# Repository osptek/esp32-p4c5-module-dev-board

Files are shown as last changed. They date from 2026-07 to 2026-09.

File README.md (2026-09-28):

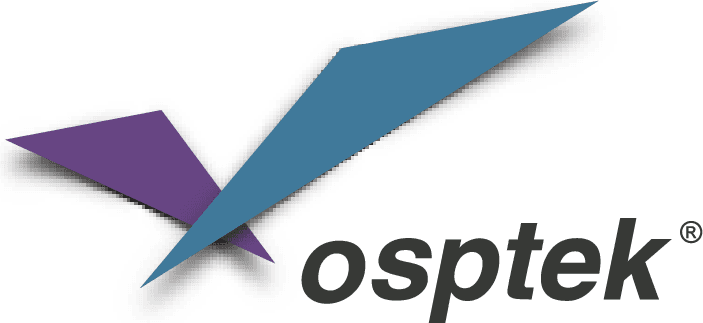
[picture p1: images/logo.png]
OSPTEK


<h1 align="center">OSPTEK ESP32-P4C5-Module 开发板</h1>

<p align="center"><b>开箱即用 · 多功能扩展 · 全接口引出</b></p>

<p align="center"><a href="./README_EN.md">English</a> | 简体中文</p>

<p align="center">
  
  
  
  
  
</p>

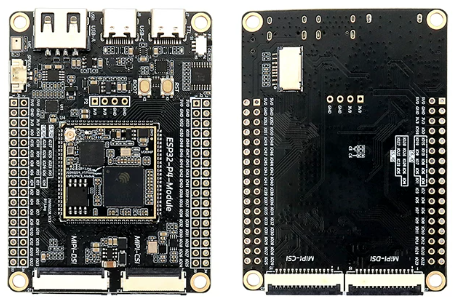
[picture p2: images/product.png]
OSPTEK ESP32-P4C5-Module 开发板产品图


## 目录

- [产品简介](#产品简介)
- [产品特性](#产品特性)
- [应用场景](#应用场景)
- [规格参数](#规格参数)
- [硬件资源](#硬件资源)
- [搭载核心板](#搭载核心板)
- [已适配屏幕](#已适配屏幕)
- [已适配摄像头](#已适配摄像头)
- [快速开始](#快速开始)
- [仓库结构](#仓库结构)
- [相关资料](#相关资料)
- [购买链接](#购买链接)
- [技术支持](#技术支持)

---

## 产品简介

OSPTEK ESP32-P4C5-Module 开发板是一款以 **ESP32-P4C5 核心板** 为核心的多功能开发平台。
底板在核心板基础上扩展出摄像头、显示屏、音频、USB 等外设接口与多重电源保护电路，
并通过 2×2×17 排针引出 ESP32-P4 的 55 个可编程 GPIO 及 ESP32-C5 的 9 个 GPIO，
省去自行设计底板的工作，可直接用于方案评估与二次开发。

核心板搭载的 ESP32-P4 内置 2 个高性能（HP）RISC-V 内核和 1 个低功耗（LP）内核，主频高达 400 MHz，
集成 JPEG 编解码器、像素处理加速器（PPA）、图像信号处理器（ISP）与 H.264 视频编码器；
配合 ESP32-C5 提供 Wi-Fi 6（2.4/5 GHz 双频）、蓝牙 5（LE）与 IEEE 802.15.4（Zigbee / Thread）无线连接。

## 产品特性

- 🚀 **开箱即用**：核心板 + 底板一体，无需自行设计底板，上电即可评估与开发
- ⚡ **高性能双核**：ESP32-P4 双核 RISC-V 处理器，主频高达 400 MHz，16 MB Flash + 32 MB PSRAM
- 🎨 **强大多媒体**：集成 JPEG 编解码、H.264 视频编码、PPA、ISP，胜任图像与视频处理
- 📶 **无线连接**：Wi-Fi 6（2.4/5 GHz 双频）、蓝牙 5（LE）、IEEE 802.15.4（Zigbee / Thread）
- 📷 **摄像头接口**：MIPI-CSI 24P 接口 + 15P 树莓派兼容接口，可直接接入 SC2336 摄像头
- 🖥️ **显示接口**：MIPI-DSI 30P 接口 + 15P 树莓派兼容接口，支持 YDP400BT001-V4 屏幕
- 🔊 **完整音频链路**：ES8311 编解码器 + NS4150 3W D 类功放 + 板载硅麦，录音放音开箱可用
- 🔌 **丰富 USB**：2 × Type-C（数据 / 调试）+ USB-A Host，支持高速 USB 2.0 切换
- 🛠️ **免接线调试**：板载 CH343P USB 转串口，模拟开关一键切换 P4 / C5 烧录目标
- 📍 **全引脚引出**：2×2×17 排针引出 ESP32-P4 的 55 个可编程 GPIO 与 ESP32-C5 的 9 个 GPIO
- 🛡️ **电源保护**：双路理想二极管防止电流倒灌，USB-A 输出口带过流与短路保护

## 应用场景

- 🖥️ HMI 人机交互
- 📷 视觉识别与图像采集
- 🎙️ 语音交互与音频处理
- 📹 视频编码与流媒体传输
- 🏠 智能家居中控面板
- 🏭 工业控制与设备监控
- 🤖 电子机器人
- 🧠 AIoT 边缘计算
- 🔌 USB 主机扩展

## 规格参数

### 主控与存储

| 项目 | 规格 |
| --- | --- |
| 核心板 | ESP32-P4C5 核心板（88 Pin 邮票孔） |
| 主控 | 乐鑫 ESP32-P4（2 × HP RISC-V + 1 × LP 内核） |
| 主频 | 高达 400 MHz |
| ROM | 128 KB HP ROM + 16 KB LP ROM |
| SRAM | 768 KB HP L2MEM + 32 KB LP SRAM + 8 KB TCM |
| Flash | 16 MB 串行 NOR Flash |
| PSRAM | 32 MB（ESP32-P4 片内叠封） |

### 无线

| 项目 | 规格 |
| --- | --- |
| 无线芯片 | ESP32-C5 |
| Wi-Fi | Wi-Fi 6（2.4 / 5 GHz 双频） |
| 蓝牙 | 蓝牙 5（LE） |
| 其他协议 | IEEE 802.15.4（Zigbee / Thread） |
| 天线 | 核心板板载 IPEX-1 天线接口 |

### 摄像头与显示

| 项目 | 规格 |
| --- | --- |
| 摄像头（正面） | MIPI-CSI 24P 0.5 mm 上下接，支持 SC2336 |
| 摄像头（背面） | MIPI-CSI 15P 1.0 mm 上下接，兼容树莓派接口 |
| 显示屏（正面） | MIPI-DSI 30P 0.5 mm 上下接，支持 YDP400BT001-V4  |
| 显示屏（背面） | MIPI-DSI 15P 1.0 mm 上下接，兼容树莓派接口 |
| 背光驱动 | SY7200 升压恒流，为 DSI 屏幕提供恒流背光 |

### 音频

| 项目 | 规格 |
| --- | --- |
| 编解码器 | ES8311（低功耗高性能单声道 Codec） |
| 功放 | NS4150（3 W 单声道 D 类） |
| 麦克风 | LMA3729T421-OA1 硅基麦克风（板载） |
| 扬声器接口 | MX1.25-2P 座子 |

### USB 与调试

| 项目 | 规格 |
| --- | --- |
| 数据口 | Type-C × 1，高速 USB 2.0（480 Mbps） |
| 调试口 | Type-C × 1，板载 CH343P USB 转 UART |
| USB Host  | USB-A × 1 |
| 通道切换  | TS3USB221ARSER 1:2 多路复用，Type-C 与 USB-A 间切换 |
| 烧录切换  | 拨动开关：往上拨烧录 ESP32-P4，往下拨烧录 ESP32-C5 |

### 电源管理

| 项目 | 规格 |
| --- | --- |
| 主电源 | 5 V 输入，TLV62569 降压至 3.3 V |
| 防倒灌 | LM66200DRLR 双路理想二极管（ORing 逻辑） |
| USB-A 输出 | MT9700 可调限流功率分配开关，带过流与短路保护 |
| 辅助电源 | 板载 1.8 V / 2.8 V LDO，供摄像头等外设使用 |

### 扩展接口

| 项目 | 规格 |
| --- | --- |
| 扩展排针  | 2 × 2×17P，2.54 mm 间距 |
| 引出 GPIO | ESP32-P4 的 55 个可编程 GPIO + ESP32-C5 的 9 个 GPIO |
| 存储扩展  | 板载 TF（microSD）卡槽 |

## 硬件资源

### 板载资源

| 器件 / 接口 | 说明 |
| --- | --- |
| 核心板 | ESP32-P4C5 核心板（邮票孔贴装，88 Pin） |
| USB 转串口  | CH343P，免驱调试串口 |
| 烧录切换 | 拨动开关 + RS2233XTSS16-Q1 四通道单刀双掷模拟开关 |
| LED 指示灯  | 板载状态指示灯 |
| 音频 Codec  | ES8311 |
| 功放 | NS4150（3 W D 类） |
| 麦克风 | LMA3729T421-OA1 硅麦（板载） |
| 扬声器座 | MX1.25-2P |
| 摄像头接口  | 正面 MIPI-CSI 24P，背面 MIPI-CSI 15P（树莓派兼容）|
| 显示接口 | 正面 MIPI-DSI 30P，背面 MIPI-DSI 15P（树莓派兼容）|
| 背光驱动 | SY7200 升压恒流 |
| USB | Type-C × 2（数据 / 调试）+ USB-A × 1（Host） |
| TF 卡槽 | microSD |
| 按键 | RST（复位）、BOOT（下载模式） |
| 扩展排针 | 2 × 2×17P，2.54 mm 间距 |

### 背面接口

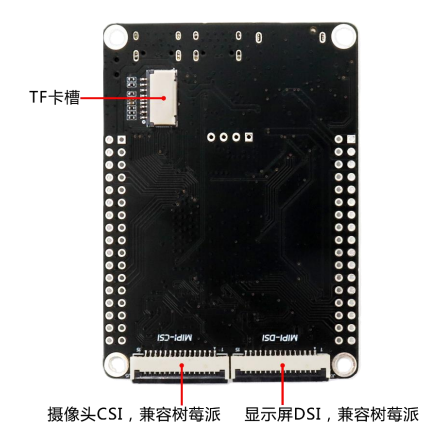
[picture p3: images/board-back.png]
ESP32-P4C5-Module 开发板背面接口标注


背面引出两个 15P 1.0 mm 的 MIPI 接口，均兼容树莓派排线；TF 卡槽位于背面上方。

### 尺寸图

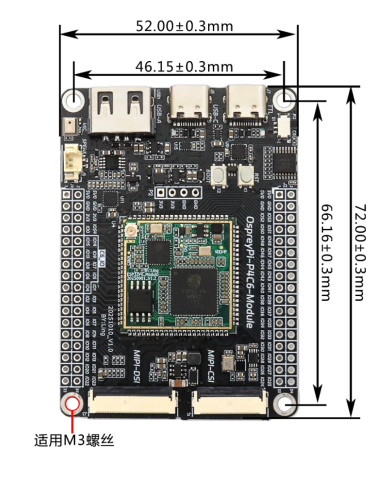
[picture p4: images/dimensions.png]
ESP32-P4C5-Module 开发板尺寸图


| 项目 | 尺寸 |
| --- | --- |
| 板卡尺寸 | 72.00 × 52.00 mm（±0.3 mm） |
| 安装孔距 | 66.16 × 46.15 mm（±0.3 mm） |
| 安装孔 | 4 × M3 螺丝孔 |

### 配套外壳

可选 **4 英寸** 前后壳（V1.0），适配本开发板 + 配套显示模组；背面开窗保留排针与扬声器孔，顶部预留摄像头开孔。

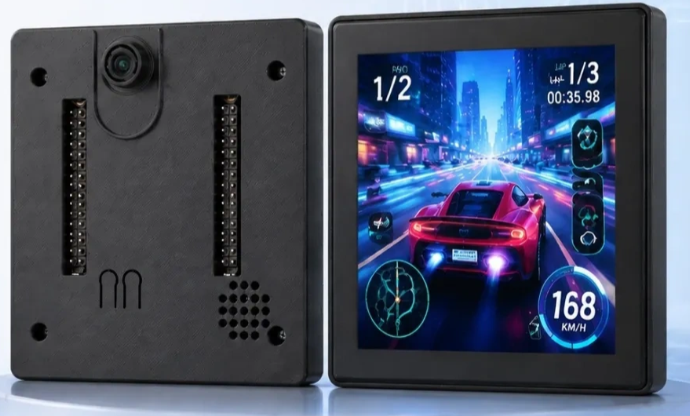
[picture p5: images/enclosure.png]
ESP32-P4C5-Module 开发板配套外壳宣传图


| 文件 | 说明 |
| ---- | ---- |
| [前壳 STEP V1.0](./docs/ESP32-P4C5-Module-Enclosure-Front-4inch-V1.0.STEP) | 4inch 前壳 |
| [后壳 STEP V1.0](./docs/ESP32-P4C5-Module-Enclosure-Back-4inch-V1.0.STEP) | 4inch 后壳 |

### 原理图

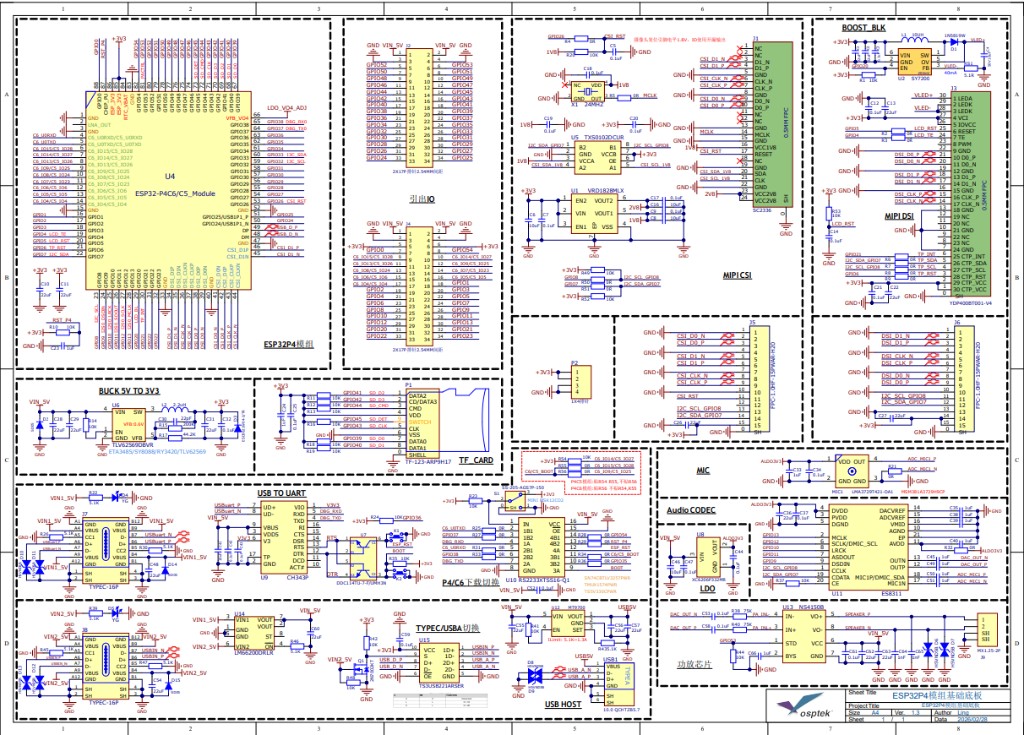
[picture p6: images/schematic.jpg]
ESP32-P4C5-Module 开发板原理图


完整原理图 PDF 见 [docs/ESP32P4模组基础底板V1.3.pdf](./docs/ESP32P4模组基础底板V1.3.pdf)。

### 硬件版本

| 日期 | 版本 | 更改内容 |
| --- | ---- | --- |
| 20251023 | V1.1 | 初始发布 |
| 20251024 | V1.2 | 优化 PCB，增加电源输入 TVS |
| 20260228 | V1.3 | MIPI-CSI 接口复位上拉改为 1.8 V，IO 建议使用开漏输出；底板兼容 P4C6 与 P4C5 模组 |

## 搭载核心板

本开发板搭载 **ESP32-P4C5 核心板**（`esp32-p4c5-core-board`），核心板引脚全部引出。
核心板的规格参数、引脚定义等详细资料见其独立仓库：

- GitHub：<https://github.com/osptek/esp32-p4c5-core-board>
- Gitee：<https://gitee.com/osptek/esp32-p4c5-core-board>

## 已适配屏幕

本开发板通过 **MIPI-DSI** 接口驱动屏幕（正面 30P 0.5 mm / 背面 15P 1.0 mm 树莓派兼容）。
下列型号可与本板对接使用，详细资料见对应仓库：

| 尺寸 | 分辨率 | 类型 | 驱动 IC | GitHub | Gitee |
| ---- | --- | ---- | --- | --- | ----- |
| 1.6″ | 480×480 | AMOLED | ST7802 | [链接](https://github.com/osptek/amoled-1.6-480x480-mipi-st7802) | [链接](https://gitee.com/osptek/amoled-1.6-480x480-mipi-st7802) |
| 1.73″ | 466×466 | AMOLED | CO5300 | [链接](https://github.com/osptek/amoled-1.73-466x466-mipi-co5300) | [链接](https://gitee.com/osptek/amoled-1.73-466x466-mipi-co5300) |
| 2.0″ | 460×460 | AMOLED | CO5300 | [链接](https://github.com/osptek/amoled-2.0-460x460-mipi-co5300) | [链接](https://gitee.com/osptek/amoled-2.0-460x460-mipi-co5300) |
| 2.1″ | 480×480 | TFT | ST77922 | [链接](https://github.com/osptek/tft-2.1-480x480-mipi-st77922) | [链接](https://gitee.com/osptek/tft-2.1-480x480-mipi-st77922) |
| 2.13″ | 410×502 | AMOLED | ST7801 | [链接](https://github.com/osptek/amoled-2.13-410x502-mipi-st7801) | [链接](https://gitee.com/osptek/amoled-2.13-410x502-mipi-st7801) |
| 2.76″ | 480×480 | TFT | ST7701 | [链接](https://github.com/osptek/tft-2.76-480x480-mipi-st7701) | [链接](https://gitee.com/osptek/tft-2.76-480x480-mipi-st7701) |
| 2.95″ | 480×854 | TFT | ST7701 | [链接](https://github.com/osptek/tft-2.95-480x854-mipi-st7701) | [链接](https://gitee.com/osptek/tft-2.95-480x854-mipi-st7701) |
| 3.13″ | 376×960 | TFT | GC9503CV | [链接](https://github.com/osptek/tft-3.13-376x960-mipi-gc9503cv) | [链接](https://gitee.com/osptek/tft-3.13-376x960-mipi-gc9503cv) |
| 3.19″ | 262×928 | AMOLED | CO6300 | [链接](https://github.com/osptek/amoled-3.19-262x928-mipi-co6300) | [链接](https://gitee.com/osptek/amoled-3.19-262x928-mipi-co6300) |
| 3.42″ | 258×960 | TFT | AXS15231B | [链接](https://github.com/osptek/tft-3.42-258x960-mipi-axs15231b) | [链接](https://gitee.com/osptek/tft-3.42-258x960-mipi-axs15231b) |
| 3.82″ | 280×1020 | TFT | AXS15231B | [链接](https://github.com/osptek/tft-3.82-280x1020-mipi-axs15231b) | [链接](https://gitee.com/osptek/tft-3.82-280x1020-mipi-axs15231b) |
| 3.95″ | 480×480 | TFT | ST7102 | [链接](https://github.com/osptek/tft-3.95-480x480-mipi-st7102) | [链接](https://gitee.com/osptek/tft-3.95-480x480-mipi-st7102) |
| 3.97″ | 480×800 | TFT | GC9503CV | [链接](https://github.com/osptek/tft-3.97-480x800-mipi-gc9503cv) | [链接](https://gitee.com/osptek/tft-3.97-480x800-mipi-gc9503cv) |
| 4.0″ | 720×720 | TFT | ST7703 | [链接](https://github.com/osptek/tft-4.0-720x720-mipi-st7703) | [链接](https://gitee.com/osptek/tft-4.0-720x720-mipi-st7703) |
| 4.3″ | 480×800 | TFT | ST7102 | [链接](https://github.com/osptek/tft-4.3-480x800-mipi-st7102) | [链接](https://gitee.com/osptek/tft-4.3-480x800-mipi-st7102) |
| 4.58″ | 424×1280 | TFT | JD9261 | [链接](https://github.com/osptek/tft-4.58-424x1280-mipi-jd9261) | [链接](https://gitee.com/osptek/tft-4.58-424x1280-mipi-jd9261) |
| 10.1″ | 800×1280 | TFT | JD9366 | [链接](https://github.com/osptek/tft-10.1-800x1280-mipi-jd9366) | [链接](https://gitee.com/osptek/tft-10.1-800x1280-mipi-jd9366) |

## 已适配摄像头

本开发板通过 **MIPI-CSI** 接口接入摄像头（正面 24P 0.5 mm / 背面 15P 1.0 mm 树莓派兼容）。
下列型号可与本板对接使用：

| 型号 | 接口 | GitHub | Gitee |
| ---- | ---- | --- | ----- |
| SC2336 | MIPI CSI | [链接](https://github.com/osptek/camera-mipi-csi-sc2336) | [链接](https://gitee.com/osptek/camera-mipi-csi-sc2336) |
| OV2710 | MIPI CSI | [链接](https://github.com/osptek/camera-mipi-csi-ov2710) | [链接](https://gitee.com/osptek/camera-mipi-csi-ov2710) |

## 快速开始

本开发板基于 **ESP-IDF** 官方生态开发，环境安装与烧录请参考乐鑫文档：

- [ESP-IDF 快速入门 · ESP32-P4（中文）](https://docs.espressif.com/projects/esp-idf/zh_CN/latest/esp32p4/get-started/)
- [ESP-IDF Get Started · ESP32-P4（英文）](https://docs.espressif.com/projects/esp-idf/en/latest/esp32p4/get-started/)

不装 ESP-IDF 时可先烧录下面合并包，验证开发板。

**烧录目标：** ESP32-C5。拨动开关**往下拨到 C5**，不要拨到 P4。

| 文件 | 烧录地址 | 说明 |
| ---- | --- | ---- |
| [`firmware/ESP32C5_2.12.9_0X0.bin`](./firmware/ESP32C5_2.12.9_0X0.bin) | `0x0`（合并包） | C5 侧固件 2.12.9 |

> 合并包请烧到 **`0x0`**，不要当成应用分区去烧 `0x10000`。

## 仓库结构

```
esp32-p4c5-module-dev-board/
├── README.md          # 产品说明（本文档）
├── README_EN.md       # 英文说明
├── docs/              # 使用指南、原理图、外壳 STEP、摄像头/天线等资料
├── firmware/          # 预编译固件（烧 C5 · 0x0）
└── images/            # README 及文档使用的图片
```

## 相关资料

### 本产品资料

- [ESP32-P4-Module 使用指南（中文，含原理图）](./docs/ESP32-P4-Module_使用指南2026.09.10（含原理图）.pdf)
- [ESP32-P4-Module User Guide（英文）](./docs/ESP32-P4-Module_User%20Guide%2020260910.pdf)
- [ESP32P4 模组基础底板原理图 V1.3](./docs/ESP32P4模组基础底板V1.3.pdf)
- [4 英寸外壳前壳 STEP V1.0](./docs/ESP32-P4C5-Module-Enclosure-Front-4inch-V1.0.STEP)
- [4 英寸外壳后壳 STEP V1.0](./docs/ESP32-P4C5-Module-Enclosure-Back-4inch-V1.0.STEP)
- [C5 预编译固件 2.12.9（烧 `0x0`）](./firmware/ESP32C5_2.12.9_0X0.bin)

### 配套外设资料

- [SC2336 数据手册](./docs/SC2336_数据手册_V0.7(1).pdf)
- [ESP32-P4 Camera 资料](./docs/ESP32-P4-Camera.pdf)
- [C5 双频天线资料](./docs/C5双频天线%20.pdf)

### 芯片资料（乐鑫官方）

- [ESP32-P4 数据手册 v1.3（中文）](https://documentation.espressif.com/esp32-p4-chip-revision-v1.3_datasheet_cn.html)
- [ESP32-P4 数据手册 v1.3（英文）](https://documentation.espressif.com/esp32-p4-chip-revision-v1.3_datasheet_en.html)
- [ESP32-P4 技术参考手册 v1.3（中文）](https://documentation.espressif.com/esp32-p4-chip-revision-v1.3_technical_reference_manual_cn.pdf)
- [ESP32-P4 技术参考手册 v1.3（英文）](https://documentation.espressif.com/esp32-p4-chip-revision-v1.3_technical_reference_manual_en.pdf)
- [ESP32-P4 产品主页（中文）](https://www.espressif.com/zh-hans/producttype/esp32-p4)
- [ESP32-P4 产品主页（英文）](https://www.espressif.com/en/producttype/esp32-p4)
- [ESP32-C5 数据手册（中文）](https://documentation.espressif.com/esp32-c5_datasheet_cn.html)
- [ESP32-C5 数据手册（英文）](https://documentation.espressif.com/esp32-c5_datasheet_en.html)
- [ESP32-C5 产品主页（中文）](https://www.espressif.com/zh-hans/products/socs/esp32-c5)
- [ESP32-C5 产品主页（英文）](https://www.espressif.com/en/products/socs/esp32-c5)

### 开发指南

- [ESP-IDF 编程指南 · ESP32-P4（中文）](https://docs.espressif.com/projects/esp-idf/zh_CN/latest/esp32p4/index.html)
- [ESP-IDF 编程指南 · ESP32-P4（英文）](https://docs.espressif.com/projects/esp-idf/en/latest/esp32p4/index.html)
- [ESP-IDF 快速入门 · ESP32-P4（中文）](https://docs.espressif.com/projects/esp-idf/zh_CN/latest/esp32p4/get-started/)
- [ESP-IDF 快速入门 · ESP32-P4（英文）](https://docs.espressif.com/projects/esp-idf/en/latest/esp32p4/get-started/)

## 购买链接

<p align="center">
  
  &nbsp;&nbsp;
  
</p>

**国内（淘宝）**

- 店铺：[鱼鹰光电工厂店](https://shop110742373.taobao.com/)

**海外（AliExpress）**

- 店铺：[OSPTEK Official Store](https://www.aliexpress.com/store/1105701619)

---

## 技术支持

如有技术问题或合作需求，欢迎通过以下方式联系我们：

- 📧 技术支持 / 产品咨询：<luyu@osptek.com>
- 🐧 QQ 技术交流群：**985881096**
- 🌐 公司官网：<https://osptek.com/>
- 有任何问题，都可以在本仓库 Issues 中提问

---

<p align="center"><sub>© 2026 OSPTEK 鱼鹰光电 · 本仓库资料采用 CC BY 4.0 许可</sub></p>

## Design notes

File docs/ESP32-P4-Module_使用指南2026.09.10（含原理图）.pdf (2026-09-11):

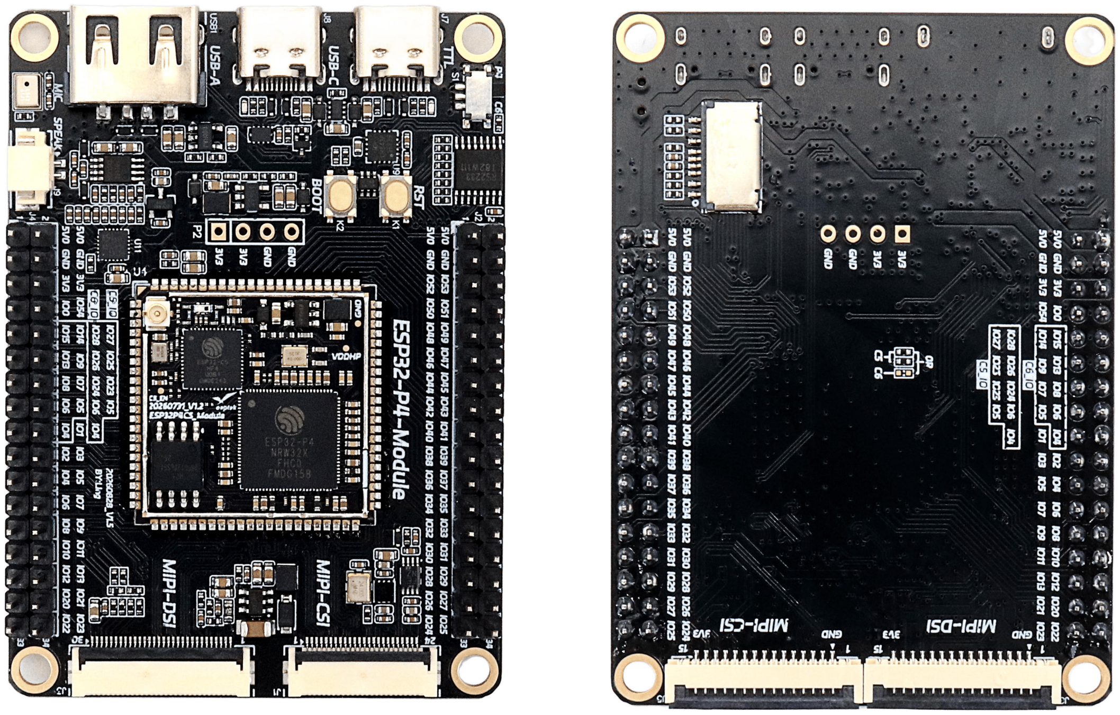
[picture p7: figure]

# 鱼鹰光电 | 咨询热线：0755-26810170 | 网址：www.yuyinglcd.com

# ESP32-P4-Module

# 支持 Wi-Fi 6 和蓝牙模块

# ESP32-P4-Module 是 一 款 高 性 能 、 多 功 能 的 嵌 入 式 核 心 系 统 模 块 。 其 设 计 核 心 为

# ESP32P4C6/ESP32P4C5 核心板。

# 本模块提供了极其丰富的外设接口与功能单元，包括摄像头、显示屏、音频、USB 以及多种电源保

# 护电路，专为需要复杂人机交互、多媒体处理、多协议无线连接和高速数据通信的先进物联网应用而设

# 计。它极大地简化了产品开发流程，为 AIoT（人工智能物联网）、多媒体处理、工业控制及复杂人机

# 交互应用提供了一个高度集成、稳定可靠的开发平台。

# ESP32-P4-Module

# 功能特性

# 搭载 RISC-V 32 位双核与单核处理器的高性能 MCU

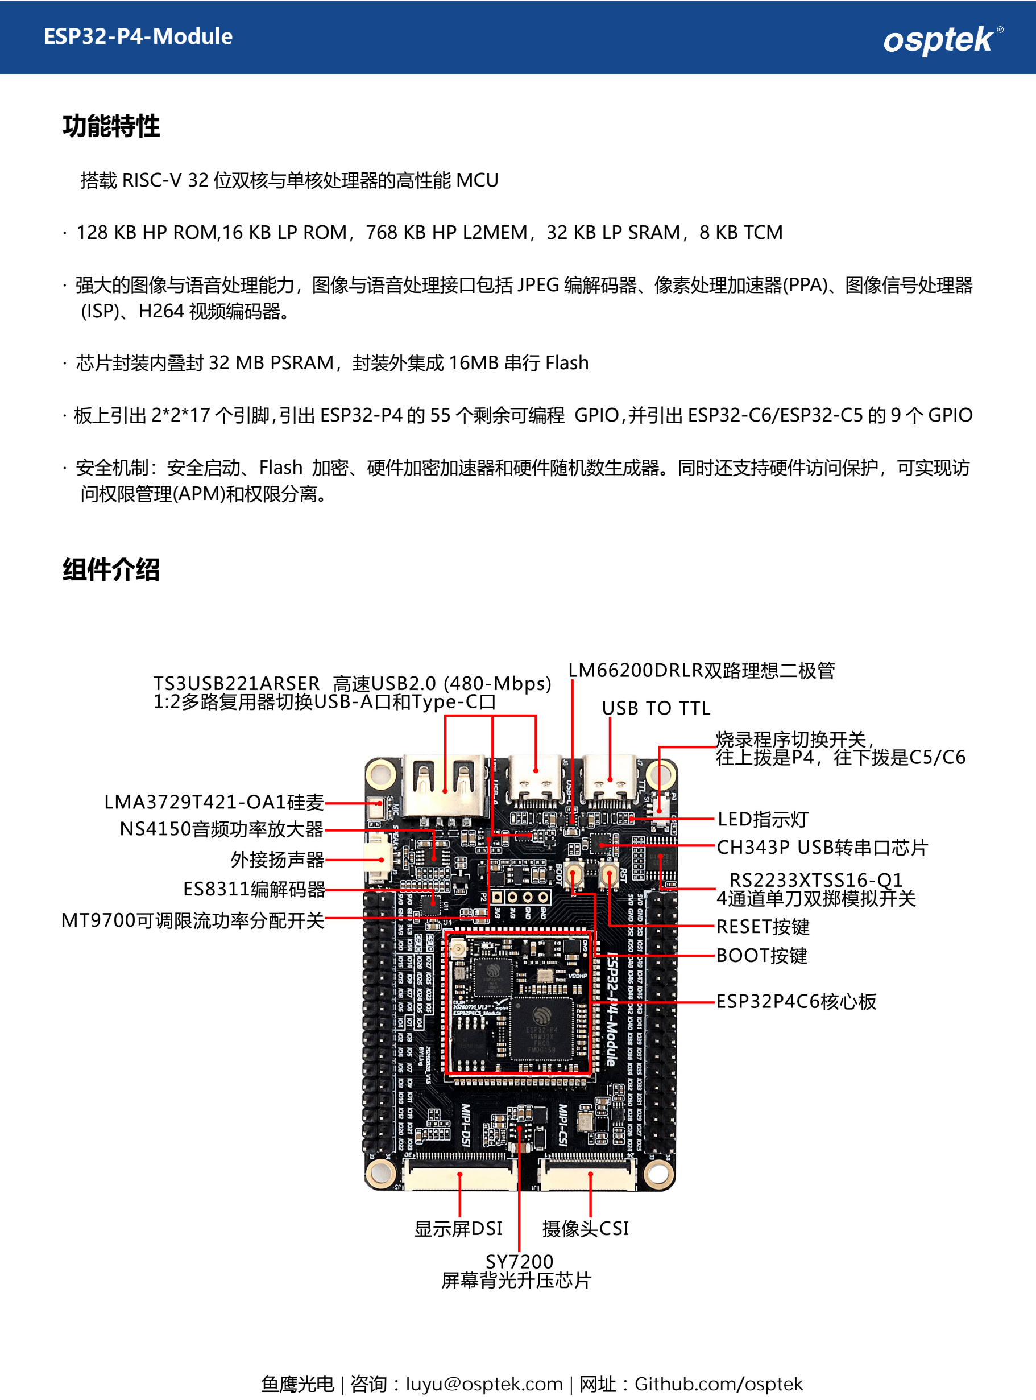
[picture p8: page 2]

# - 128 KB HP ROM,16 KB LP ROM，768 KB HP L2MEM，32 KB LP SRAM，8 KB TCM

# - 强大的图像与语音处理能力，图像与语音处理接口包括 JPEG 编解码器、像素处理加速器(PPA)、图像信号处理器 (ISP)、H264 视频编码器。

# - 芯片封装内叠封 32 MB PSRAM，封装外集成 16MB 串行 Flash

# - 板上引出 2*2*17 个引脚，引出 ESP32-P4 的 55 个剩余可编程 GPIO，并引出 ESP32-C6/ESP32-C5 的 9 个 GPIO

# - 安全机制：安全启动、Flash 加密、硬件加密加速器和硬件随机数生成器。同时还支持硬件访问保护，可实现访 问权限管理(APM)和权限分离。 组件介绍

# 鱼鹰光电 | 咨询：luyu@osptek.com | 网址：Github.com/osptek

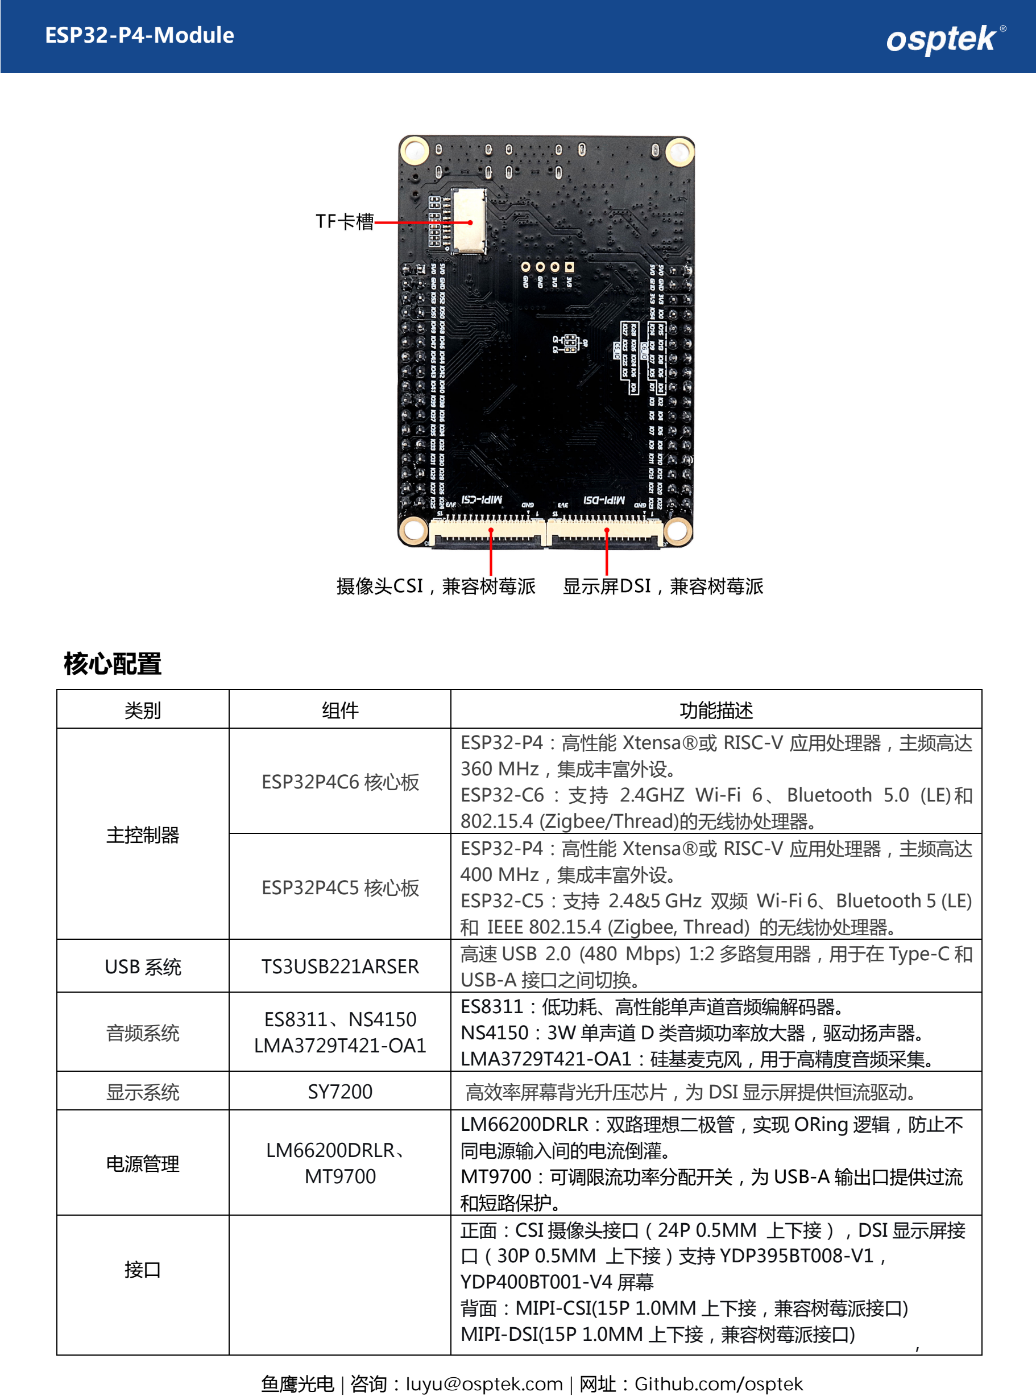
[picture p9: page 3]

# 核心配置

类别 | 组件 | 功能描述
主控制器 | ESP32P4C6 核心板 | ESP32-P4：高性能 Xtensa®或 RISC-V 应用处理器，主频高达 360 MHz，集成丰富外设。 ESP32-C6：支持 2.4GHZ Wi-Fi 6、Bluetooth 5.0 (LE)和 802.15.4 (Zigbee/Thread)的无线协处理器。
| ESP32P4C5 核心板 | ESP32-P4：高性能 Xtensa®或 RISC-V 应用处理器，主频高达 400 MHz，集成丰富外设。 ESP32-C5：支持 2.4&5 GHz 双频 Wi-Fi 6、Bluetooth 5 (LE) 和 IEEE 802.15.4 (Zigbee, Thread) 的无线协处理器。
USB 系统 | TS3USB221ARSER | 高速 USB 2.0 (480 Mbps) 1:2 多路复用器，用于在 Type-C 和 USB-A 接口之间切换。
音频系统 | ES8311、NS4150 LMA3729T421-OA1 | ES8311：低功耗、高性能单声道音频编解码器。 NS4150：3W 单声道 D 类音频功率放大器，驱动扬声器。 LMA3729T421-OA1：硅基麦克风，用于高精度音频采集。
显示系统 | SY7200 | 高效率屏幕背光升压芯片，为 DSI 显示屏提供恒流驱动。
电源管理 | LM66200DRLR、 MT9700 | LM66200DRLR：双路理想二极管，实现 ORing 逻辑，防止不 同电源输入间的电流倒灌。 MT9700：可调限流功率分配开关，为 USB-A 输出口提供过流 和短路保护。
接口 | | 正面：CSI 摄像头接口（24P 0.5MM 上下接），DSI 显示屏接 口（30P 0.5MM 上下接）支持 YDP395BT008-V1， YDP400BT001-V4 屏幕 背面：MIPI-CSI(15P 1.0MM 上下接，兼容树莓派接口) MIPI-DSI(15P 1.0MM 上下接，兼容树莓派接口) ，

# 产品尺寸

# 必备硬件

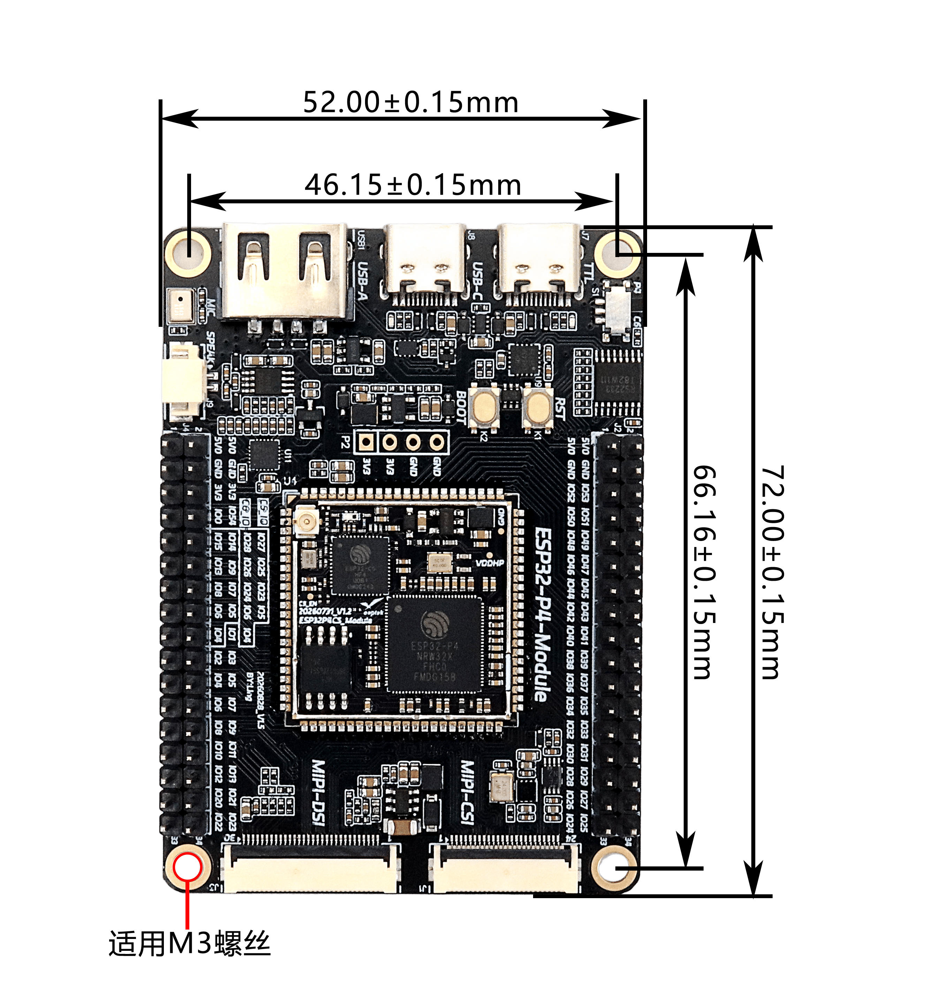
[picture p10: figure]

# 1 x ESP32-P4-module 1 x USB 2.0 数据线（标准 A 型转 Micro-B 型） 1 x 电脑（Windows、Linux 或 macOS）

# 注意：请确保使用适当的 USB 数据线。部分数据线仅可用于充电，无法用于数据传输和编程。

# 开发与调试

# 软件设置：使用 Visual Studio Code，ESP-IDF 进行设置，固件下载可使用 flash_download_tool

# 串口调试：通过板载的 USB TO TTL 接口（CH343）连接电脑，在设备管理器中识别到串行端口即可进行日志打 印和调试。

# 固件下载：通过 RS2233 模拟开关，可分别选择对 ESP32-P4 或 ESP32-C6 核心进行固件烧录

# 软件开发：支持 ESP-IDF 开发框架，可开发 P4 核心的应用程序。

# 硬件版本

日期 | 版本 | 更改内容
20251023 | V1.1 | 1. 初始发布
20251024 | V1.2 | 2. 优化 PCB，增加电源输入 TVS
20260228 | V1.3 | 3. MIPI_CSI 接口复位上拉改为 1.8V，IO 建议使用开漏输出 4. 底板兼容 P4C6 模组与 P4C5 模组
20260430 | V1.4 | 5. 调整 C5 的 boot 引脚 IO27 上拉， IO28 与 C6 的 boot IO9 相连
20260828 | V1.5 | 6. 调整 C5 的 boot 引脚 IO27 28 与 C6 的 boot IO9 相连

# 原理图

1

2

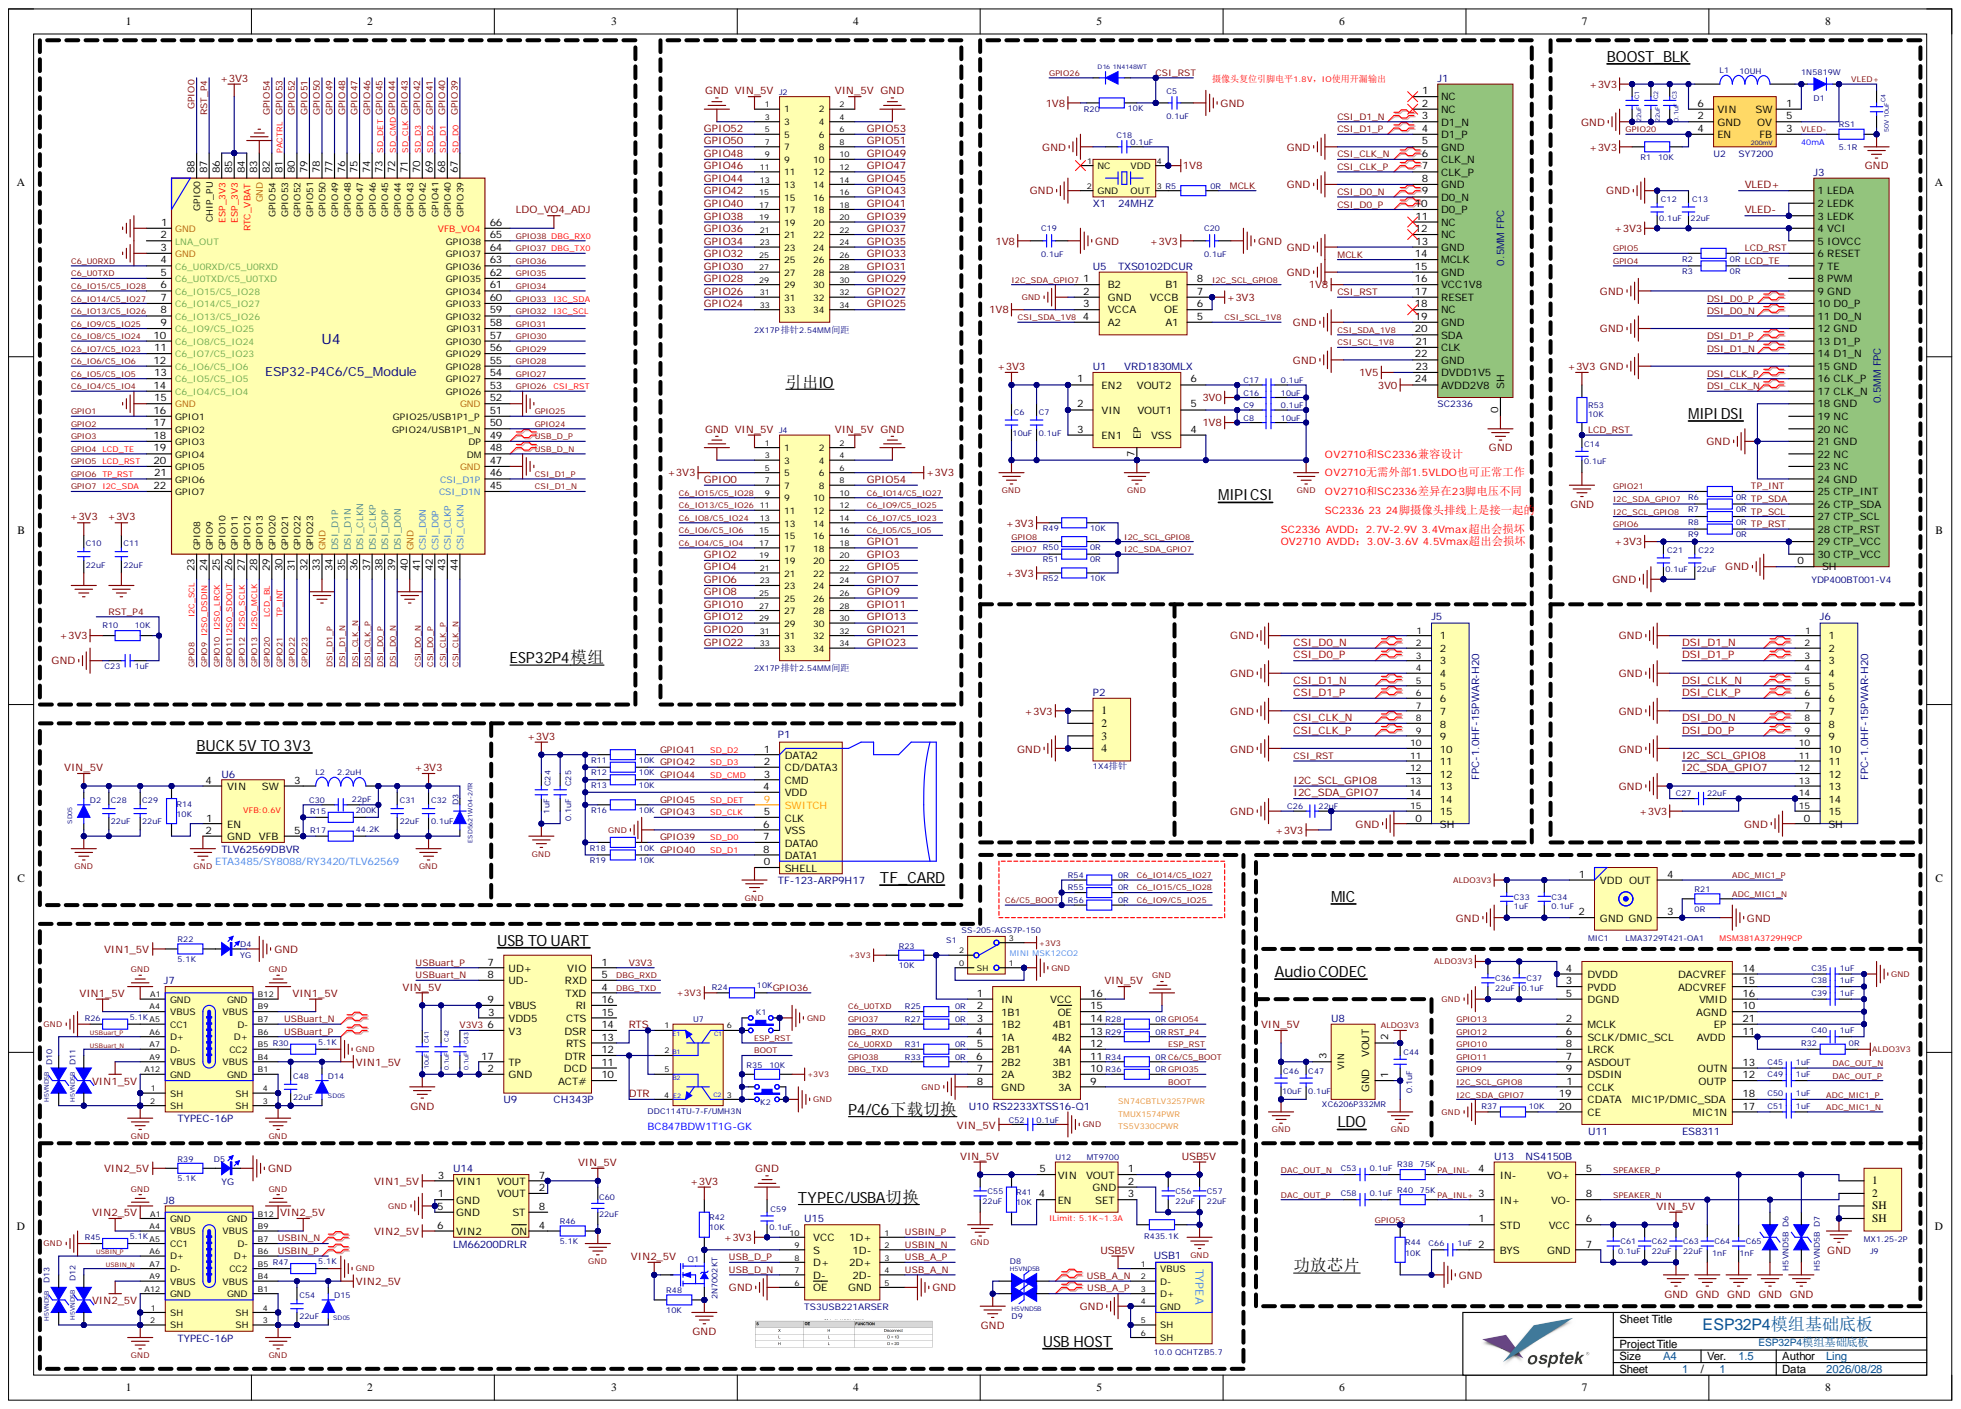
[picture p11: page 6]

CSI_D1N 45 CSI_D1P 46 GND 47 DM 48 DP 49 GPIO24/USB1P1_N 50 GPIO25/USB1P1_P 51 GND 52

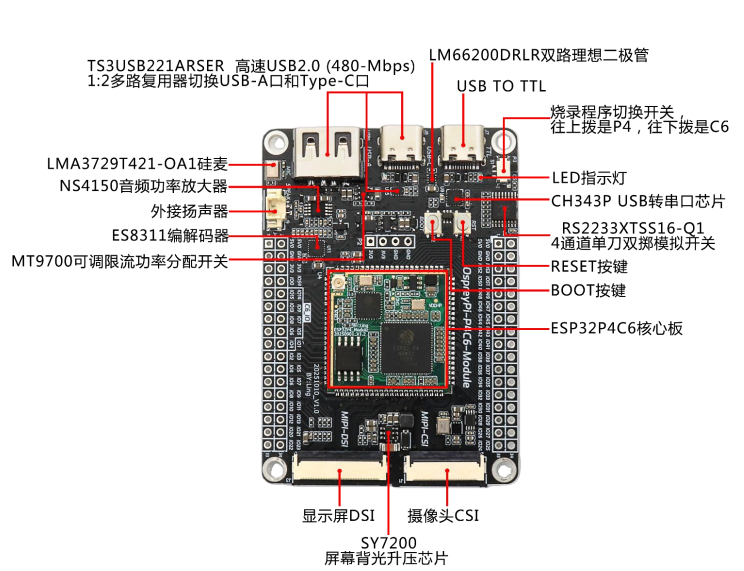
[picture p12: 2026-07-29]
images/board-front.png

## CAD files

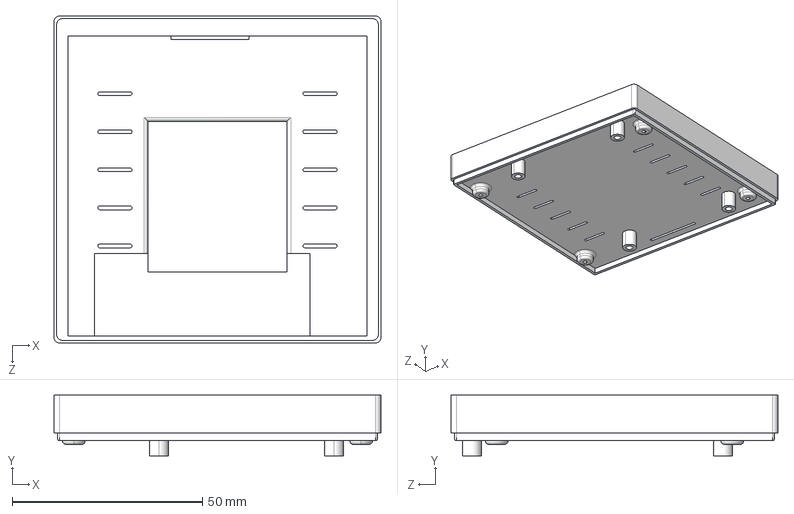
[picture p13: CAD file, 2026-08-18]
docs/ESP32-P4C5-Module-Enclosure-Front-4inch-V1.0.STEP
85.9 x 16.0 x 85.9 mm

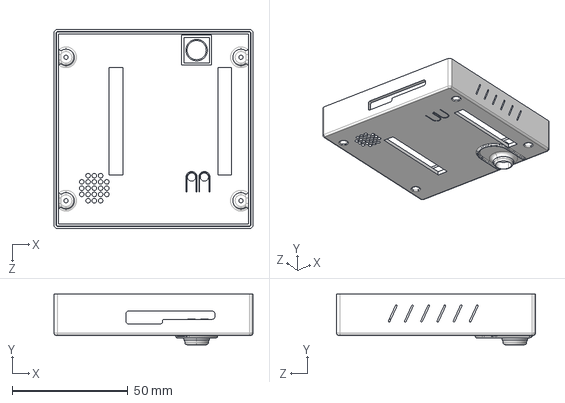
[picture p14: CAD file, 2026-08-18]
docs/ESP32-P4C5-Module-Enclosure-Back-4inch-V1.0.STEP
85.9 x 21.8 x 85.9 mm

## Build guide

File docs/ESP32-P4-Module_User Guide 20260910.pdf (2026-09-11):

# ESP32-P4 Module

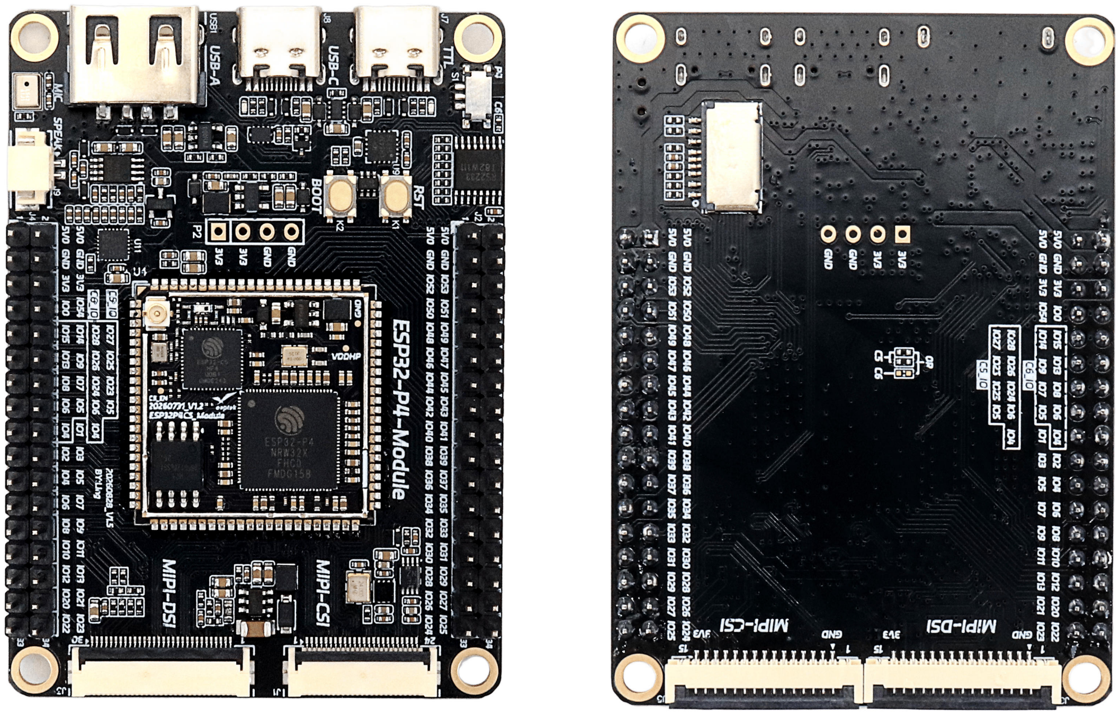
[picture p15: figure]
Pins

# ESP32-P4-Module

# Wi-Fi 6 and Bluetooth Module Support

1013
10s
107
103

# MIPI-CSI

# ESP32-P4-Module

# The ESP32-P4-Module is a high-performance, multi-functional embedded core system

module. Its design is centred around the ESP32P4C6/ESP32P4C5 Core board.

This module features an extensive array of peripheral interfaces and functional units,

# including camera, display, audio, USB, and various power protection circuits. Engineered

for advanced IoT applications demanding complex HMI, multimedia processing,

# multi-protocol wireless connectivity, and high-speed data communication,it significantly streamlines product development. The module offers a highly integrated,stable,and

reliable development platform for AIoT, multimedia processing, industrial control, and sophisticated HMI applications.

# Component Overview

# Features

# High-performance MCU featuring RISC-V 32-bit dual-core and single-core processors

# - 128 KB HP ROM, 16 KB LP ROM, 768 KB HP L2MEM, 32 KB LP SRAM, 8 KB TCM

- Powerful image and audio processing capabilities, with interfaces including a JPEG codec, pixel processing accelerator (PPA), image signal processor (ISP) and H.264 video encoder.
- 32 MB PSRAM stacked within the chip package, with 16 MB of serial Flash integrated outside the package
- 2×2×17 pins are brought out on the board, providing access to the 55 remaining programmable GPIOs of the ESP32-

# P4, as well as 9 GPIOs from the ESP32-C6/ESP32-C5

Security mechanisms: Secure boot, Flash encryption, hardware cryptographic accelerator and hardware random number generator. It also supports hardware access protection, enabling access policy management (APM) and privilege separation.

# ESP32-P4 Module ESP32-P4-Module

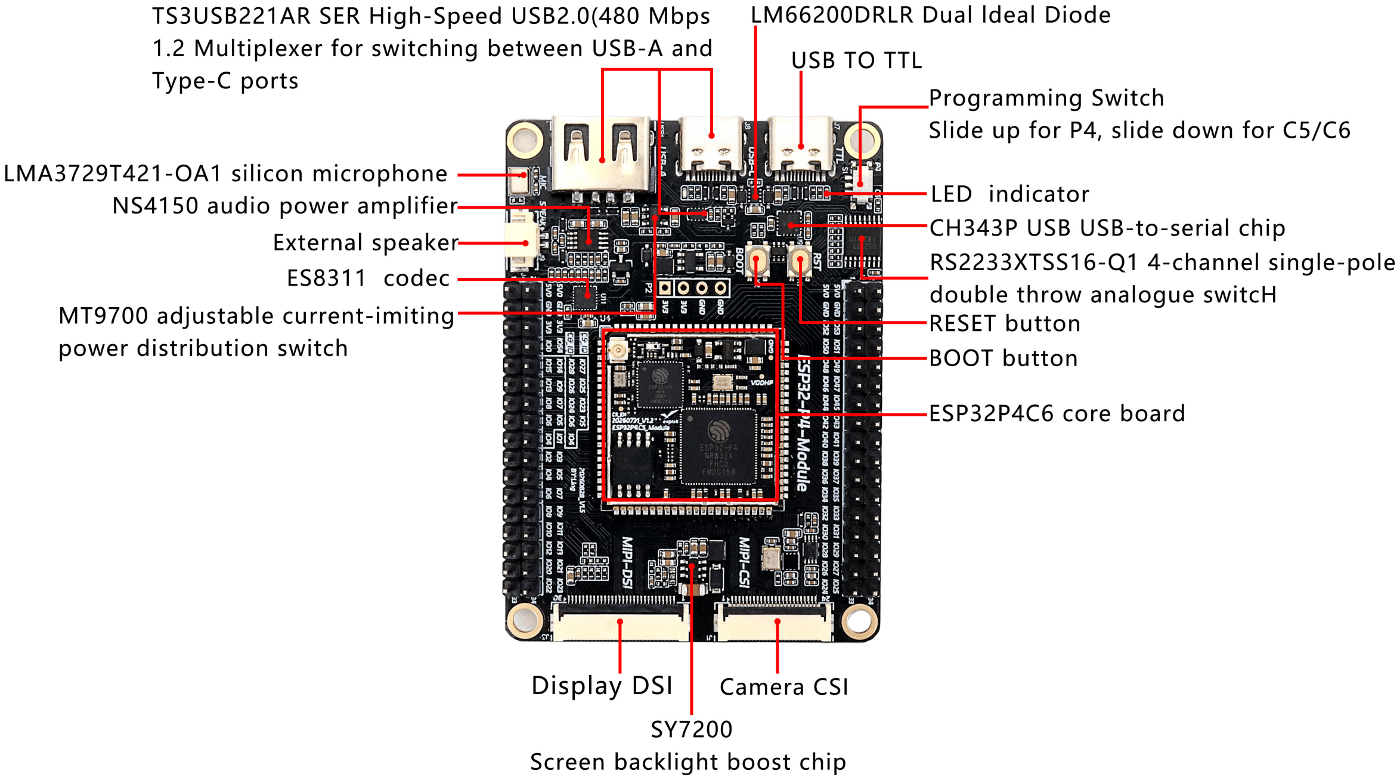
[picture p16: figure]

# Osprey Optoelectronics | Inquiry: luyu@osptek.com | Website: Github.com/osptek

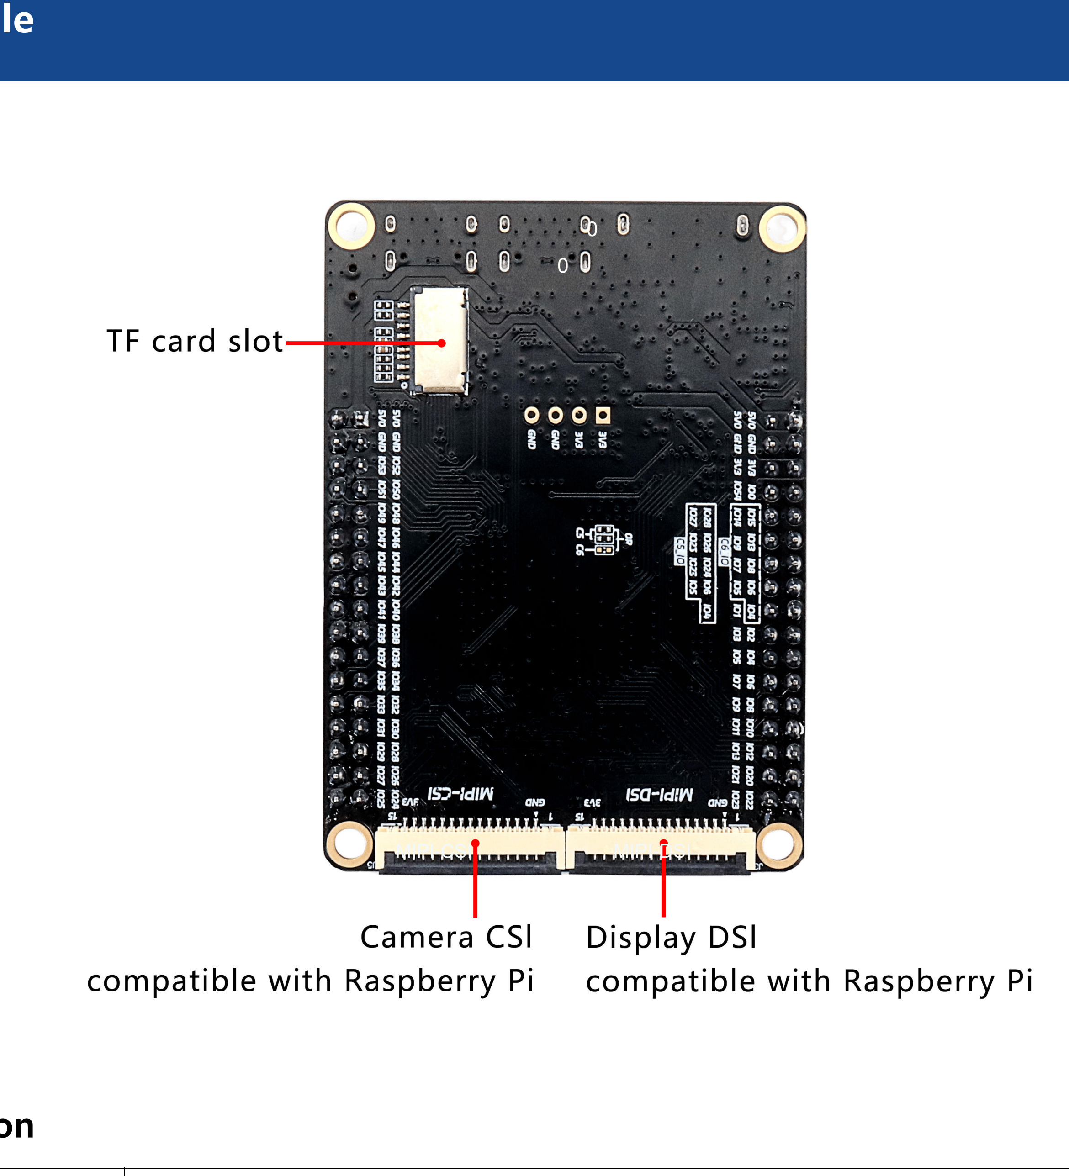
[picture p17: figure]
MIPI-CSI; MIPI-DSI

Category | Component | Function Description
Main Controller | ESP32P4C6 Core Board | ESP32-P4: High-performance Xtensa® or RISC-V application processor, clocked at up to 360 MHz, with a rich set of integrated peripherals. ESP32-C6: Wireless coprocessor supporting 2.4 GHz Wi-Fi 6, Bluetooth 5.0 (LE) and 802.15.4 (Zigbee/Thread).
| ESP32P4C5 Core Board | ESP32-P4: High-performance Xtensa® or RISC-V application processor, clocked at up to 400 MHz, with a rich set of integrated peripherals. ESP32-C5: Wireless coprocessor supporting dual-band 2.4 & 5 GHz Wi-Fi 6, Bluetooth 5 (LE) and IEEE 802.15.4 (Zigbee, Thread).
USB System | TS3USB221AR SER | High-speed USB 2.0 (480 Mbps) 1:2 multiplexer for switching between Type-C and USB-A interfaces.
Audio System | ES8311, NS4150, LMA3729T421-OA1 | ES8311: Low-power, high-performance mono audio codec. NS4150: 3W mono Class D audio power amplifier for driving speakers. LMA3729T421-OA1: Silicon microphone for high-precision audio capture.
Display System | SY7200 | High-efficiency screen backlight boost chip, providing constant-current drive for DSI displays.
Power Management | LM66200DRLR, MT9700 | LM66200DRLR: Dual ideal diodes implementing OR-gate logic to prevent current backflow between different power inputs. MT9700: Adjustable current-limiting power distribution switch providing overcurrent and short- circuit protection for USB-A output ports.
Interfaces | | Front: CSI camera interface (24-pin 0.5mm pitch, top-to-bottom), DSI display interface (30-pin 0.5mm pitch, top-to-bottom) supporting the YDP395BT008-V1 and YDP400BT001-V4 screen. Rear:MIPI-CSI (15-pin, 1.0 mm pitch, top/bottomconnection, compatible with Raspberry Pi interface), MIPI-DSI (15-pin, 1.0 mm pitch, top/bottom connection,compatible with Raspberry Pi interface)

# Core Configuration

# Product Dimensions

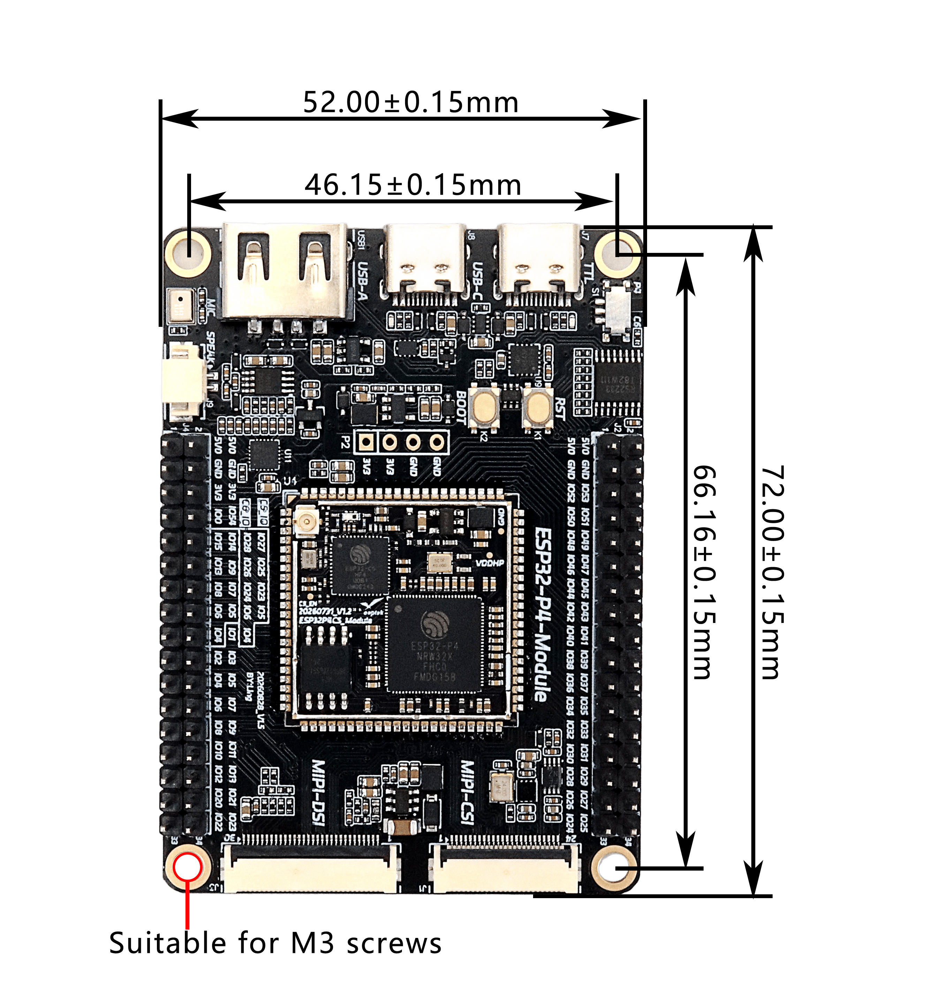
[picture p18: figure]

# Required hardware

# 1 x ESP32-P4-module 1 x USB 2.0 cable (Standard Type-A to Micro-B) 1 x computer (Windows, Linux or macOS)

Note: Please ensure you use a suitable USB cable. Some cables are designed for charging only and cannot be used for data transfer or programming.

# Development and Debugging

Software setup: Use Visual Studio Code and ESP-IDF for configuration; the flash_download_tool can be used to download

# the firmware

Serial Debugging: Connect to a computer via the on-board USB-to-TTL interface (CH343); once the serial port is recognised in Device Manager, you can proceed with logging and debugging.

Firmware Download: Using the RS2323 emulation switch, you can select to flash firmware to either the ESP32-P4 or

# ESP32-C6 core

Software Development: Supports the ESP-IDF development framework, enabling the development of applications for the P4 core.

# Hardware Version

# Schematic

Date | Version | Changes
20251023 V1.1 | | 1. Initial release
20251024 V1.2 | | 2. Optimised PCB,added power input TVS
20260228 V1.3 | | 3. Set MIPI_CSI reset pull-up to 1.8V; use open-drain output for the I/O. 4. The base board supports both P4C6 and P4C5 modules.
20260430 | V1.4 | 5. Adjust C5's boot pin: pull up IO27, and connect IO28 to C6's boot IO9.
20260828 | V1.5 | 6. Adjust C5's boot pin: connect IO27 and IO28 to C6's boot IO9.

1

2


CSI_D1N 45 CSI_D1P 46 GND 47 DM 48 DP 49 GPIO24/USB1P1_N 50 GPIO25/USB1P1_P 51 GND 52

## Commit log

2026-07-29 feat(docs): add ESP32-P4C5-Module dev board documentation
    Publish Chinese and English READMEs with specs, hardware resources,
    compatible MIPI displays/cameras, and purchase links.
2026-08-18 docs: add 4-inch enclosure STEP files and promo image
    [ESP32-P4C5-Module-Enclosure-Back-4inch-V1.0.STEP, ESP32-P4C5-Module-Enclosure-Front-4inch-V1.0.STEP]
2026-09-10 docs(guide): replace P4-Module user guide with 2026.09.10
    - add Chinese guide with schematic and English user guide
    - remove 2026.03.26 Chinese guide
2026-09-14 docs(dev-board): update display module repository links
2026-09-21 docs(firmware): add P4 merged image 2.12.9 at 0x0
    - flash ESP32-P4 with the switch set to P4
2026-10-20 docs(enclosure): add 3.95-inch camera flip-case STEP
    - add the 180-degree flip case model for the 3.95-inch display and camera
    - link it from the Chinese and English README
